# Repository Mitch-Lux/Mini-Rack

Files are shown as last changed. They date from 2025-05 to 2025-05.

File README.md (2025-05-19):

This is a page to track the build guidance for my mini rack project.

## Concept
This Project was inspired by the "[Project MINI RACK](https://www.youtube.com/watch?v=y1GCIwLm3is&ab_channel=JeffGeerling)" from Jeff Geerling

Whilst I liked the idea of the mini rack that [GeeekPi 4U](https://www.amazon.com/GeeekPi-Cabinet-Equipment-RackMate-Rackmount/dp/B0DPGZPTPP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,aps,130&sr=8-1&linkCode=sl1&tag=mmjjg-20&linkId=96cf07e1d07bd0da81caae2ab0ceefd0&language=en_US&ref_=as_li_ss_tl) I also didn't have the money to buy a rack, especially with such a small heigh in U's.

Most of my equipment is scavenged, pre-owned, gifted, or ebayed at the lowest price possible, meaning most of it will not fit in a single U of rack height. Due to this, I wanted to build a rack to take my homelab (read that as E-waste if you want) equipment and keep it somewhat organised. 

I know that there are several excellent 3D printed racks around, but I have my concerns about the amount of weight that some of them could take, and my 10 year old HP promicro isn't getting any lighter, so my requirements were:
- Cheap: I want this build to be as cheap as possible  
- Reliable: Structural elements of the rack should where possible be metal to allow for older heavier equipment. 
- Accessible: If someone else sees this idea and wants to make their own, lets minimise the amount of tools and specialist equipment you need to put the rack body together. 
            As a caviat to this specialist shelves are't counted as technically they are not needed, and metal shelves available online could replace them for non-racked components where needed. 
- Modifiable: The rack is made for homelabbing, but it doesn't have to be. By using modular, adjustable or off the shelf components, anyone can make a rack to fit their personal bespoke needs.
- Movable: The Rack should be on wheels so it can be parked out of the way most of the time, but easily accessible on all sides should the need arise.

## Who is this for:
- If you saw Jeff Geerling's Mini Rack video and github and thought, "I want one of those!", and similtanously that you didn't have £100+ to drop on a 4U rack
- If you have some homelab equipment and want to make a mini-rack from scratch to meet your specific needs.
- If you want to make a rack unit for something else, like Audio equipment, or just don't need a full sized rack. 

## Bill Of Materials
I have tired to cover any off the shelf components used in my build here:
[Link](https://github.com/Mitch-Lux/Mini-Rack/tree/main/Bill%20Of%20Materials)

## Diagrams:
This page is to cover how the rack is put together from the components:
Link

## Basic Construction:
Covering actuall assembly of the rack
Link

## 3D Print files:
This covers all the 3D print files I made or modified to complete my rack.
[Here](https://github.com/Mitch-Lux/Mini-Rack/tree/main/3D-Printfiles)

## Extended Development:
This covers uneccesary extensions I have added to my homelab rack to make it into what I wanted it to be, including the quick release side panels, 3D printed shevles customised for components, fan supports and cowlings, handles, etc....
[Here](https://github.com/Mitch-Lux/Mini-Rack/tree/main/Extended%20Development)

## FAQ
<details>
<summary>Expand Here</summary>

IOU1FAQ

</details>

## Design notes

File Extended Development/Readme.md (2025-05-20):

# Extra features
Below are a list of optional upgrades I have made to the rack since the basic framework was in place:

## Casters, AKA wheels:
I used these Caster whheels for the bottom of my rack to allow for ease of movement 
[SL Heavy Duty Braked 50mm Swivel Castor Wheels Trolley – Caster Wheels Set of 4 – Rubbered Castors for Furniture – Upto 200KG ](https://www.amazon.co.uk/dp/B01MT3DZ73?ref_=ppx_hzsearch_conn_dt_b_fed_asin_title_1)
These can be attached to the join of the 2020T aluminium extrusion at the bottom of the rack, with 3 mounting points without having to make any alterations to the base of the rack (assuming your casters have a square mounting plate with holes in each corner).

## Handles for the rack:
I have attached a copy of the handles found at the link below to the front top and bottom, and rear top and bottom of the rack to enable easy movement on the casters. 
[Hex Pattern Handle Collection](https://makerworld.com/en/models/138456-hex-pattern-handle-collection#profileId-156939) by BaGooN
These are then attached to the 2020T aluminium extrusion with M6 bolts passing into m6 t-nuts

## Side Pannels:
In my case the side pannels for the minirack are made of chipboard. 
"Why? you might ask, well.... I had some lying around because I was given some offcuts for free, and this seemed like a good time to use it.
I painted the chipboard white for my rack, after cutting it to dimension. Please bear in mind if you have changed the height (or dept) of the rack you built, or the dimensions will need to be changed. 

### Rational
Assenmbling the sides provides a number of options, for ease of access to the equipment inside my rack, I wanted side pannels that could be quickly and tool-lessly detatched, and re-attached. 
To make life easier I decided to mount the pannels to the outside of the 2020T extrusion as this way I wouldn't need to cut the pannels precisely, and I wouldn't need to worry about chamfering the top edge to allow it to swing out if I made it a friction fit. 
### Purchased Components
This requires the 90 degree joint blocks found in the BOM under "[Right angle brackets](https://vi.aliexpress.com/item/1005007349855293.html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)"
Handily these come supplied with their own bolts and cage nuts, although in my case I didn't use them, because I lost them. I am not a smart man...
### 3D Printed components

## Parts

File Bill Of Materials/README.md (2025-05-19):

- [Parts List Rack strips](https://www.amazon.co.uk/dp/B07R81MBPZ?ref=ppx_yo2ov_dt_b_fed_asin_title&th=1) (I personally used the 20U (892.2mm Total Length) )
Used to provide standardised U heigh slots for Cage nuts

- [Cage Nuts](https://vi.aliexpress.com/item/4000370449729.html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)￡15.69
Used to connect items into the Rails U heigh seperated slots

- [2020 Aluminium Extrusion 2020 Aluminium Extrusion](https://vi.aliexpress.com/item/1005005893301224.html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)
4x (￡4.89) Lenght 400mm Front to Rear bracers
4x (￡3.99) Length 300mm Sideways bracers

- [L joints](https://vi.aliexpress.com/item/1005006415197962.html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) ￡5.29
 Used to sit inside the joints to keep them as close to the frame as possible 

- [Captive Nuts](https://vi.aliexpress.com/item/1005007383347166.html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)
Used to screw components into the 2020T

- [Completely unneccessary rubber covers for 2020 extrusion](https://vi.aliexpress.com/item/1005001683499330.html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)
I thought these would be a good idea, but honestly I ended up discarding most of it as the 2020T aluminimum ended up with most sides in use, but I am leaving this here so you can benefit from my mistakes.

- [Right angle brackets](https://vi.aliexpress.com/item/1005007349855293.html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) ￡4.91
Used to hold the side panels on, may be an optional component depending on if you use the same method I did for attaching components. 

- [10" shelf](https://www.amazon.co.uk/dp/B08XJXKX4R?ref=ppx_yo2ov_dt_b_fed_asin_title&th=1)  (apx $12)
Used to hold heavier items to the frame where I was not confident that printed components would be sturdy enough.

- [SL Heavy Duty Braked 50mm Swivel Castor Wheels Trolley – Caster Wheels Set of 4 – Rubbered Castors for Furniture – Upto 200KG](https://www.amazon.co.uk/dp/B01MT3DZ73?ref_=ppx_hzsearch_conn_dt_b_fed_asin_title_1)

- [2x3 Fan assembly with speed controller and wallsocket power](https://vi.aliexpress.com/item/1005004296428088.html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) ￡34.19
Used to provide updraft based cooling to the tower. This will only work if you have airflow available thorugh the centre of the tower. If you put a solid block across it, don't expect it to work.

-[Filters / Grids to go ontop of the Fan assembly](https://vi.aliexpress.com/item/1005007876973563.html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) ￡1.69
Protects the fans

Electronics- remove

- POE Switch [TP-Link Managed PoE Network Switch 5-Port Gigabit, 4 PoE+ ports up to 30 W for each PoE port and 65 W for all PoE ports, Support Network monitoring, traffic prioritization, VLAN(TL-SG105PE) Size Name: 5-port Gibabit|65W 4xPoE+](https://www.amazon.co.uk/dp/B08DVFMCK4?ref=ppx_yo2ov_dt_b_fed_asin_title&th=1)

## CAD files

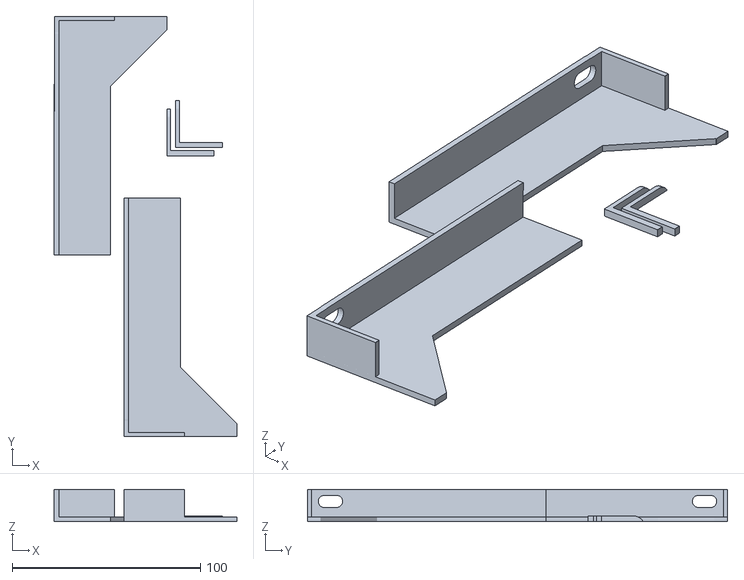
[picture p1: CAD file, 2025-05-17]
3D-Printfiles/topofrackfanmountingplate.stl
97.0 x 223.1 x 17.2

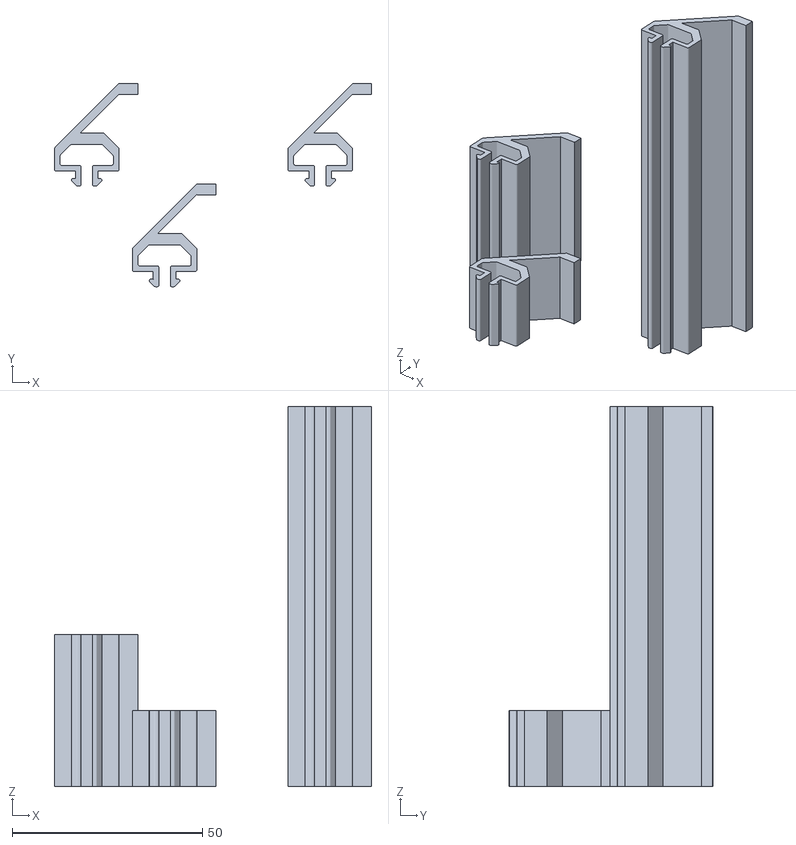
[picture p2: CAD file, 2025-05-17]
3D-Printfiles/2020extrusionclips.stl
83.5 x 53.6 x 100.0

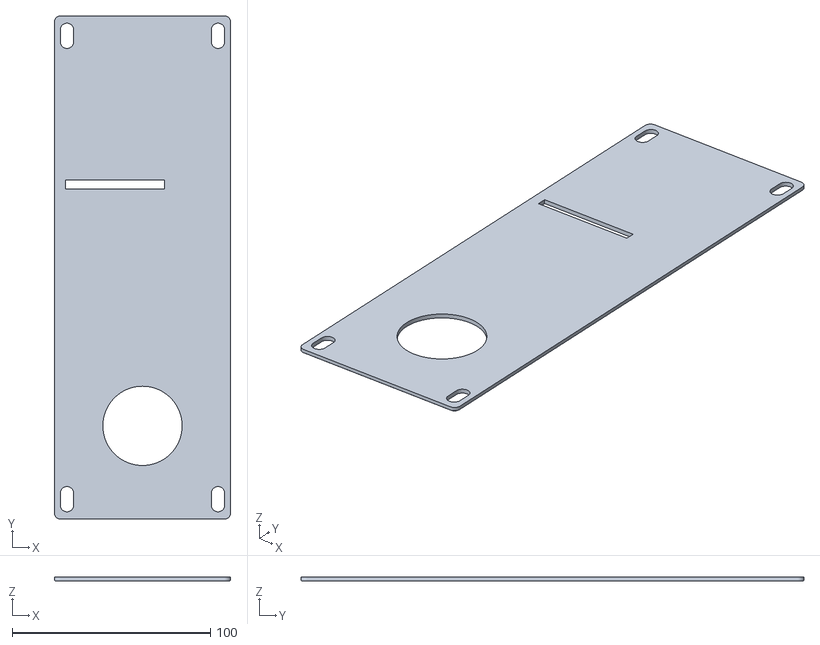
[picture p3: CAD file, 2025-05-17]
3D-Printfiles/2ublankinglatewithslitandcablepassthrough.stl
89.0 x 254.0 x 2.00

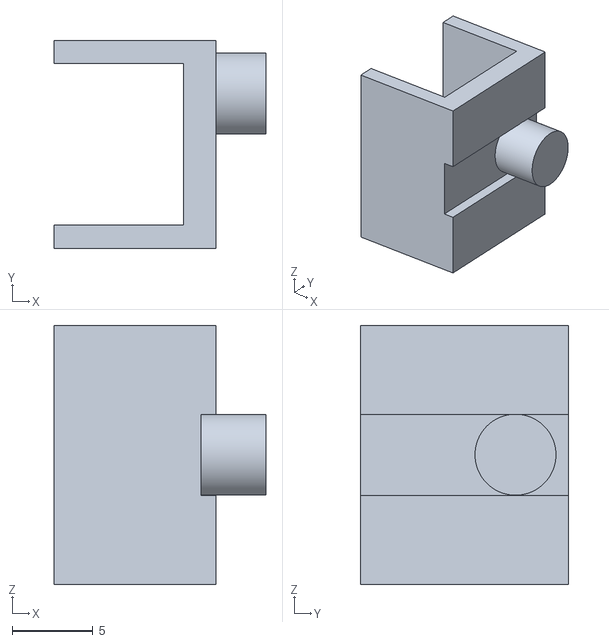
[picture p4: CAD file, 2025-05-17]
3D-Printfiles/Sidepannelbottomcup.stl
13.1 x 12.8 x 16.0

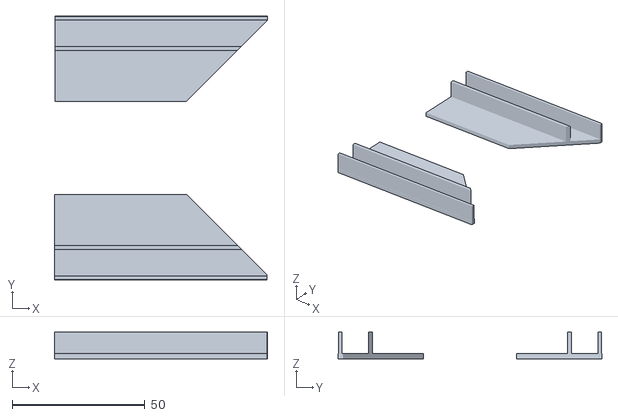
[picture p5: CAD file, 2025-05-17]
3D-Printfiles/Sidepannelaircoverstriptopleftadnright.stl
80.1 x 99.2 x 10.0

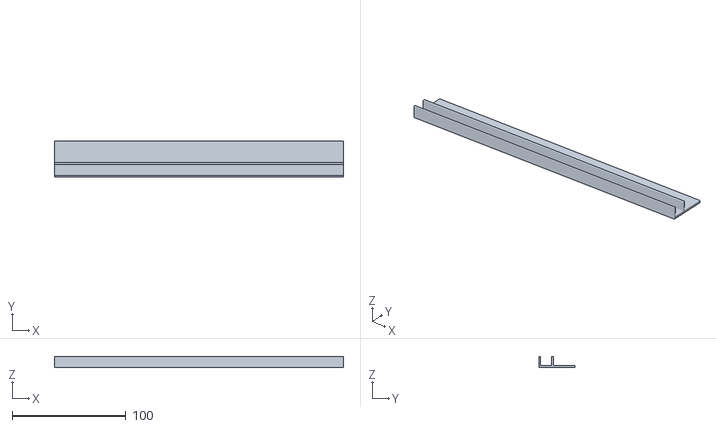
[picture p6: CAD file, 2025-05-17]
3D-Printfiles/Sidepannelaircoverstrip.stl
253.6 x 32.0 x 10.0

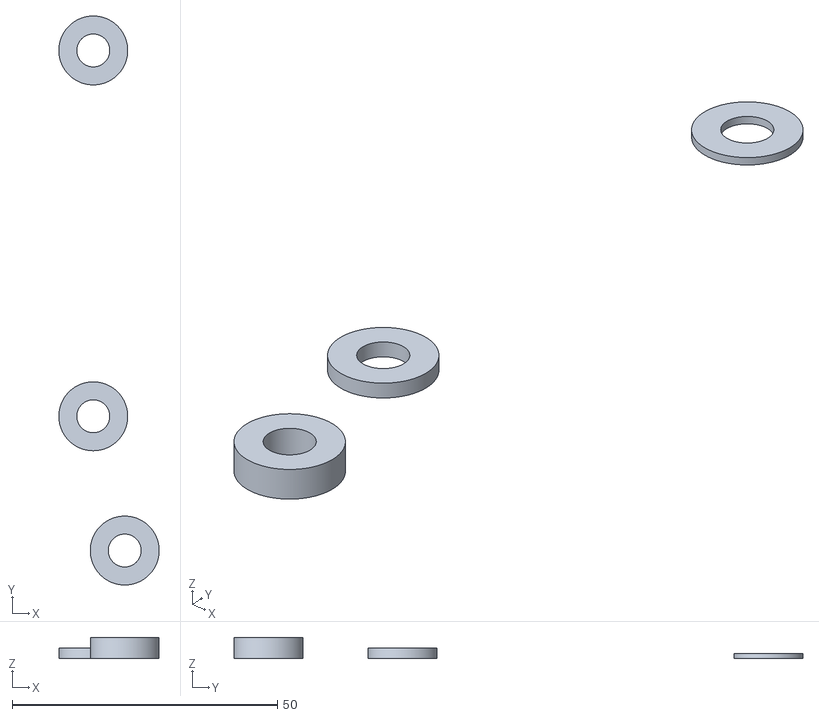
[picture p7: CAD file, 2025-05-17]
3D-Printfiles/washersfor6mmbolts.stl
18.9 x 107.3 x 4.00
